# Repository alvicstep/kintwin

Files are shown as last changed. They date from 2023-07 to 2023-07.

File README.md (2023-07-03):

# KinTwin
KinTwin is a fork of [KinBP](https://github.com/DmNosachev/KinBP). It is a drop-in replacement of a controller and thumb cluster PCB boards for [Kinesis Contoured keyboards](https://deskthority.net/wiki/Kinesis_Contoured).

## Goals
- Replace stock firmware with [QMK](https://docs.qmk.fm/#/) open source firmware
- Show clear and concise BOM (bill of materials) required for the upgrade depending on Kinesis keyboard model

## Included PCBs

||
|-|
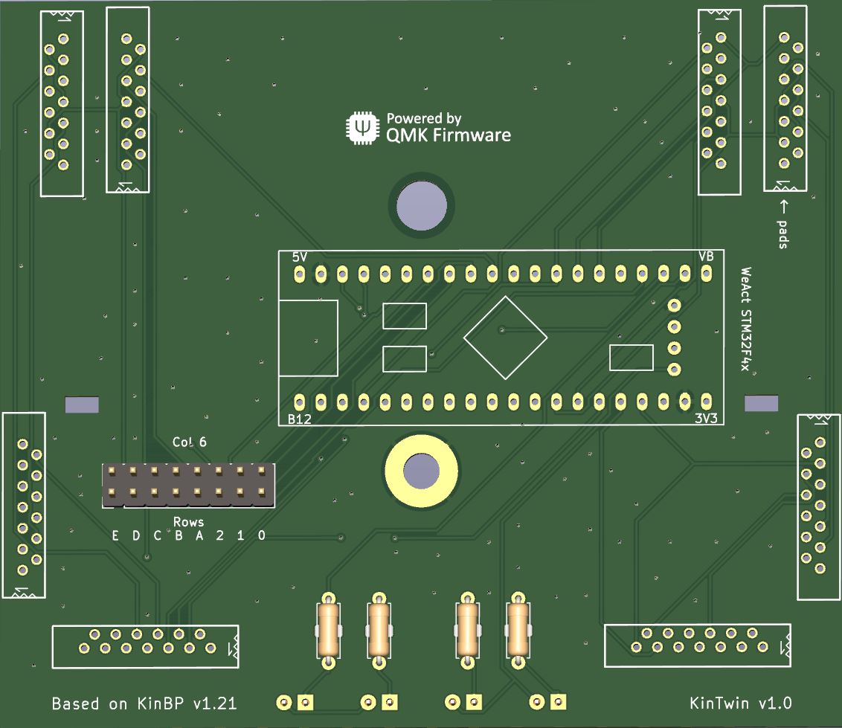
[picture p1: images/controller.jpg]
|        
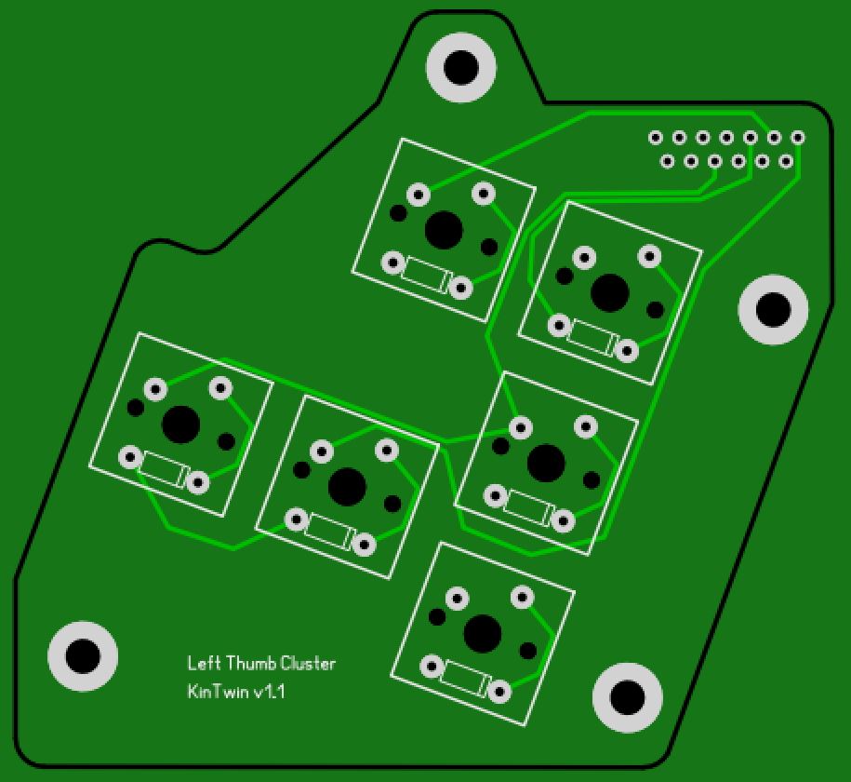
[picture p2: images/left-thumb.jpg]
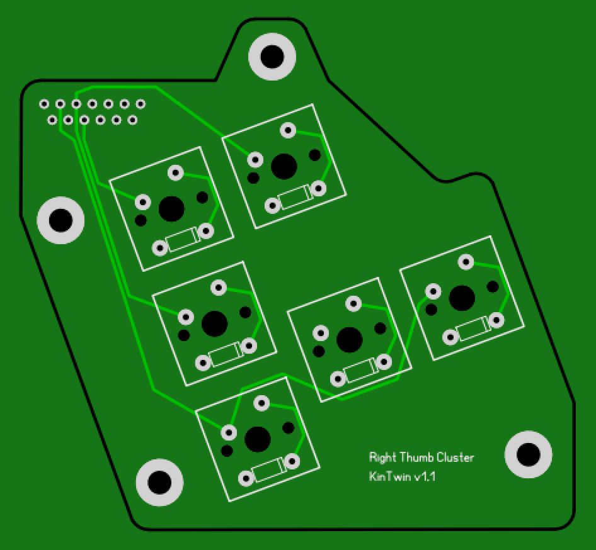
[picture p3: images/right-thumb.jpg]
| 
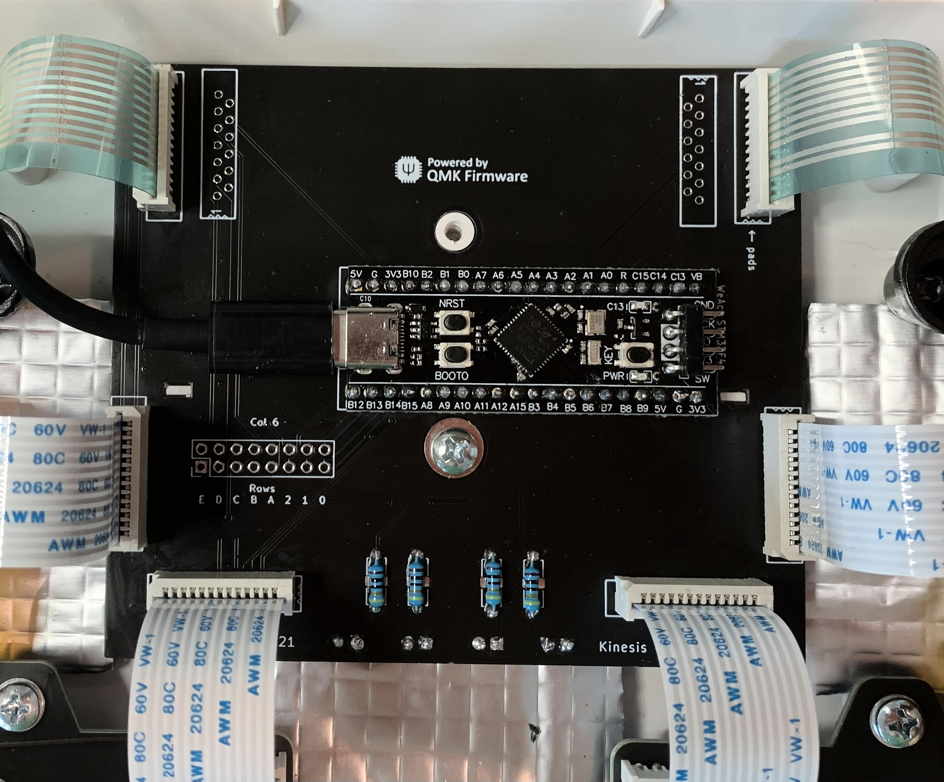
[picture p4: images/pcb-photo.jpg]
|  
> **Warning**  
> I have recently updated the design of thumb cluster PCB from v1.0 to v1.1 
> The changes are cosmetic and should not affect functionality, but I did not order the new boards to be able to confirm that they still work.  
> Changes include: 
> - moved silk screen of the FPC connector pad to the correct side
> - changed mounting holes of the FPC connector pad to be plated

## Comparison with KinBP
- The controller board is a simplified version on KinBP board. It uses **WeAct Studio STM32F401** development board
- KinTwin controller board uses only FPC connectors to interface with other PCB boards. In that regard it has the same design as stock Kinesis Advantage II
- KinTwin controller does not support 10-pin 2.54mm headers which are used to connect the controller to thumb cluster boards
- Similar to KinBP repo, KinTwin includes PCB boards for thumb clusters. They are functionally identical to stock Kinesis Advantage II. Unlike KinBP, these PCBs are not reversible (hence there are 2 of them). Also, similar to stock boards, they use through-hole diodes and FPC connectors
- The controller board was originally designed in KiCad by [DmNosachev](https://github.com/DmNosachev). KinTwin controller board is a clone of KinBP which was slightly modified by removing extra connector pads. 
- Thumb cluster boards were designed in [Sprint Layout 6.0](https://www.electronic-software-shop.com/lng/en/electronic-software/sprint-layout-60.html?language=en)

## Controller compatibility with top row PCBs, keywell PCBs and thumb cluster PCBs

|Keyboard Model |Top row PCBs|Keywell PCBs|Thumb cluster PCBs|
|---|---|---|---|
|KB600 (Advantage II) |Yes |Yes |Yes |
|KB500 (Advantage) |Yes |Yes |No  * |
|KB13x (Essential, Classic, Professional) |Yes |Yes |No  * |
|100/110/120 ** |No |No |No  * |

\* These keyboards require custom thumb cluster PCBs which are provided in the repo\
** You are likely not going to find these keyboards in the wild. They are 20+ years old

## BOM (common for all models)
|Name |Quantity  |Image  |
|---|---|---|
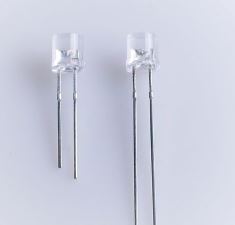
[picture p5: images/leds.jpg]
|3mm Blue LED Diodes (DC 3.0V-3.2V (IF=20mA) / 0.06 Watts / 2pin) | 4 | |
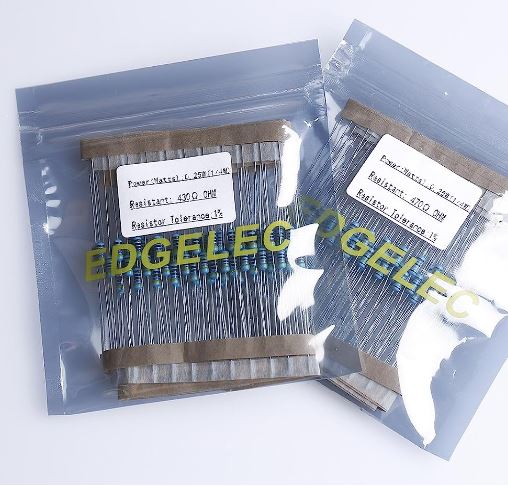
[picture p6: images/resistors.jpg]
|430ohm (For DC 6-12V) 1/4 Watt Metal Film Resistors | 4 | |
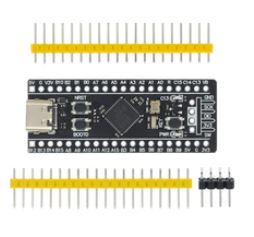
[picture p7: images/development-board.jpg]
|STM32F401 development board | 1 ||
|Controller board | 1 | |

## BOM (for model KB600)
|Name |Quantity  |Image  |
|---|---|---|
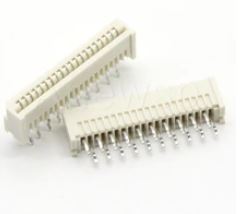
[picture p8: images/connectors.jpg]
|13-pin straight FPC connectors | 6 | |

## BOM (for model KB500) 

|Name |Quantity |Image |
|---|---|---|
|13-pin straight FPC connectors | 8 | |
|Left thumb cluster board | 1 | |
|Right thumb cluster board | 1 | |
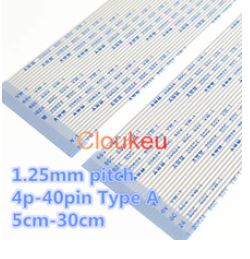
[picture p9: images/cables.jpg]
|FPC flexible flat cables (FFC1.25-60mm)  | 2 | |
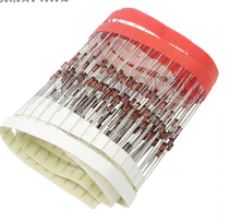
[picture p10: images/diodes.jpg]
|Diodes (1N4148 DO-35 IN4148) for thumb cluster PCBs| 12 ||
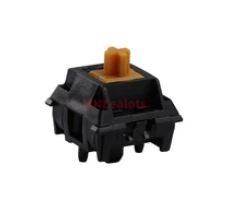
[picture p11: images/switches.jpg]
|Keyboard switches for thumb cluster PCBs | 12 | |

## BOM (for models KB13x)

|Name |Quantity |Image |
|---|---|---|
|13-pin straight FPC connectors | 6 | |
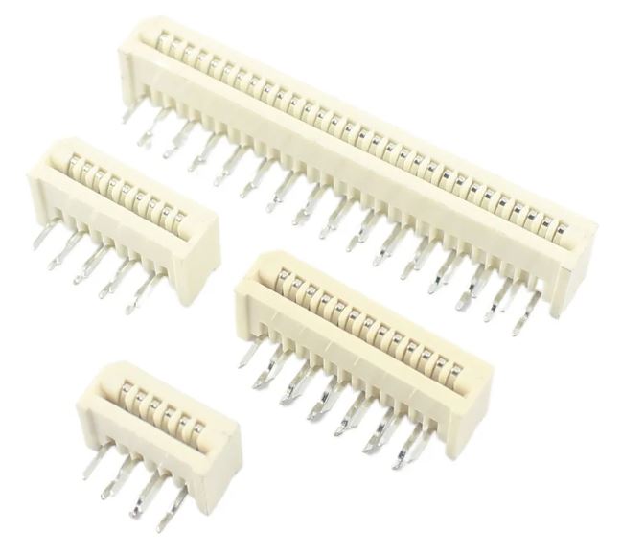
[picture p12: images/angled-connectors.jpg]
|13-pin angled FPC connectors | 2 ||  
|Left thumb cluster board | 1 | |
|Right thumb cluster board | 1 | |
|FPC flexible flat cables (FFC1.25-60mm)  | 2 | |
|Diodes (1N4148 DO-35 IN4148) for thumb cluster PCBs| 12 | |
|Keyboard switches for thumb cluster PCBs | 12 | |

## QMK Related Topics

Read about the custom QMK layout which I have designed [here](/layouts/readme.md)

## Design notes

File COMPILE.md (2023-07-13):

# Compiling/Flashing

1. I submitted PR which contains the kintwin controller files and soft_dev keypam but it is still being reviewed. There is nothing else for me to do but wait. In the meantime, you can use the forked repo which I used for PR to flash the keyboard with new keymap

    - QMK fork url: https://github.com/alvicstep/qmk_firmware/tree/kintwin
    - kintwin controller directory url: https://github.com/alvicstep/qmk_firmware/tree/kintwin/keyboards/kinesis/kintwin
	- keymap url: https://github.com/alvicstep/qmk_firmware/tree/kintwin/keyboards/kinesis/keymaps/soft_dev

2. Here is a PR that I submitted for review: https://github.com/qmk/qmk_firmware/pull/21453
 
3. There is only one controller. Controller details can be found here: https://github.com/alvicstep/kintwin

4. Compiling/flashing process is the same as for any other board. QMK documentation: https://docs.qmk.fm/#/newbs_getting_started
	- download my fork of QMK (link above)
	- install QMK MSYS in order to compile the firmware: https://msys.qmk.fm  The wizard will ask whether you want to dowload QMK. Reply "no" because you already have a forked repo.
		You will then have to point MSYS to the directory where you cloned QMK fork.
		Run the following command in MSYS: `qmk config user.qmk_home=<QMK fork directory>`
		A backslash must be escaped with another backslash in the path. Example: `qmk config user.qmk_home=C:\\git\\qmk_firmware` 
		
	- compile framework. Run the following command in QMK MSYS: `qmk compile -kb kinesis/kintwin -km soft_dev`
	- download QMK Toolbox from here: https://github.com/qmk/qmk_toolbox/releases
	- put the keyboard in bootloader mode: press "Pgrogrm" button on the keyboard. This is top right button on the keyboard
	- set path in QMK Toolbox to the "bin" file which you compiled. Click "Flash" button in QMK Toolbox
	
5. To update keymap: make changes to the keymap in the forked repo here: `/keyboards/kinesis/keymaps/soft_dev/keymap.c`
   You can use any other keymap in "keymaps" directory as your base keymap. But please make sure the keymap contains bootloader mapping (code QK_BOOT). Otherwise you will have to perform physical reset by pushing buttons on the controller board itself: Hold `'boot0'` button on MCU board, press `'reset'`, then release `'boot0'`
   
   - Run the following command in QMK MSYS: `qmk compile -kb kinesis/kintwin -km <keymap name>`
   - Flash the firmware as described above

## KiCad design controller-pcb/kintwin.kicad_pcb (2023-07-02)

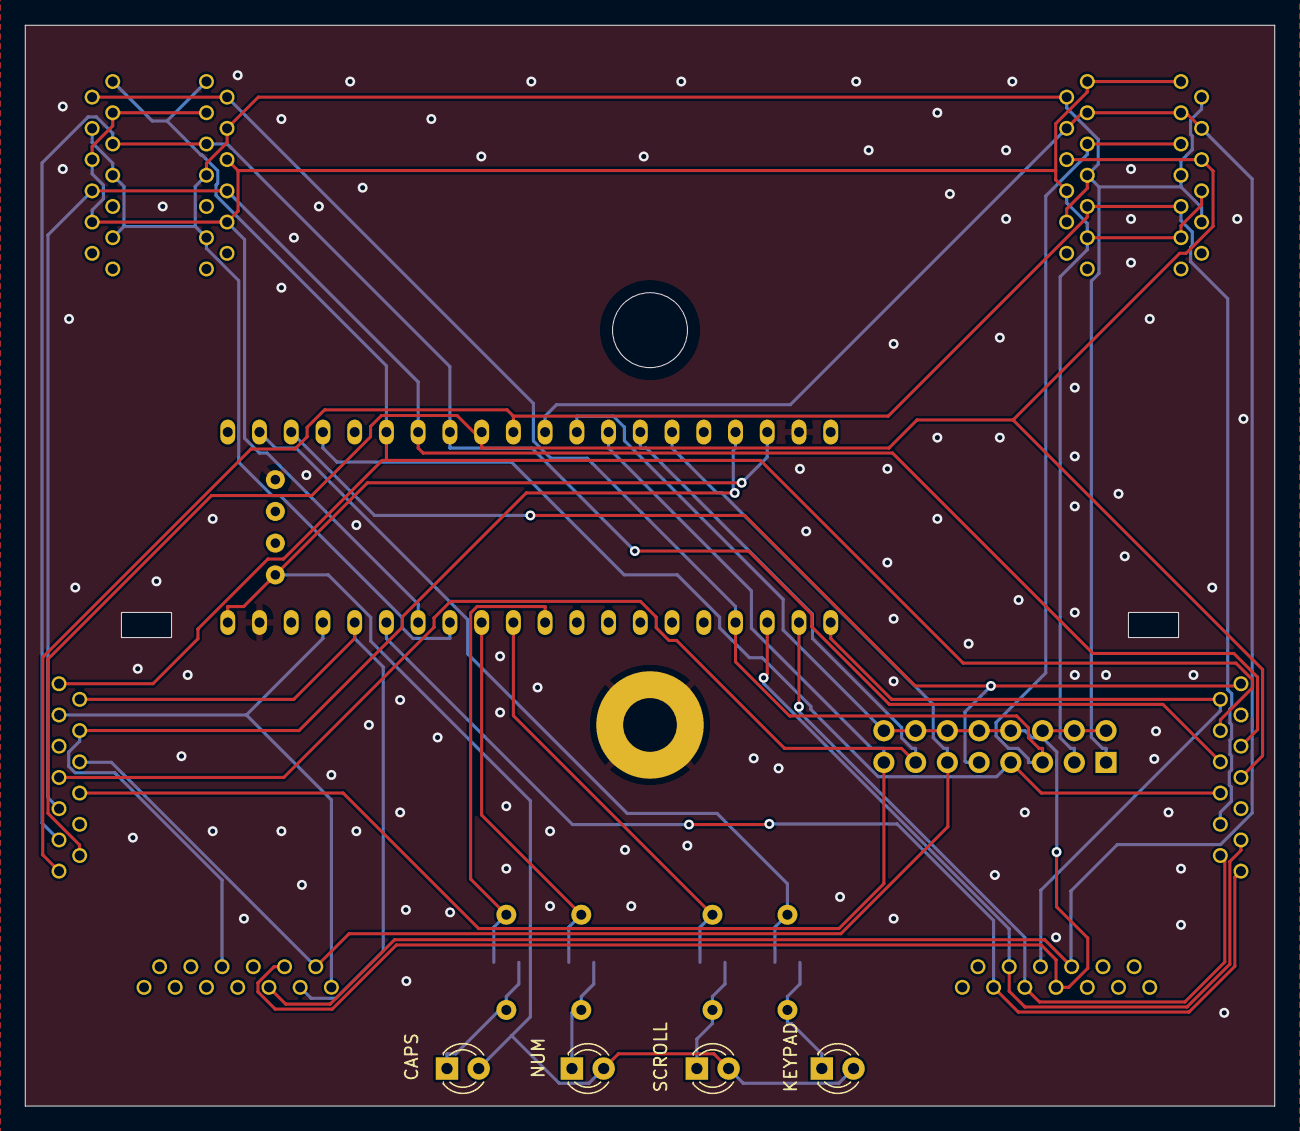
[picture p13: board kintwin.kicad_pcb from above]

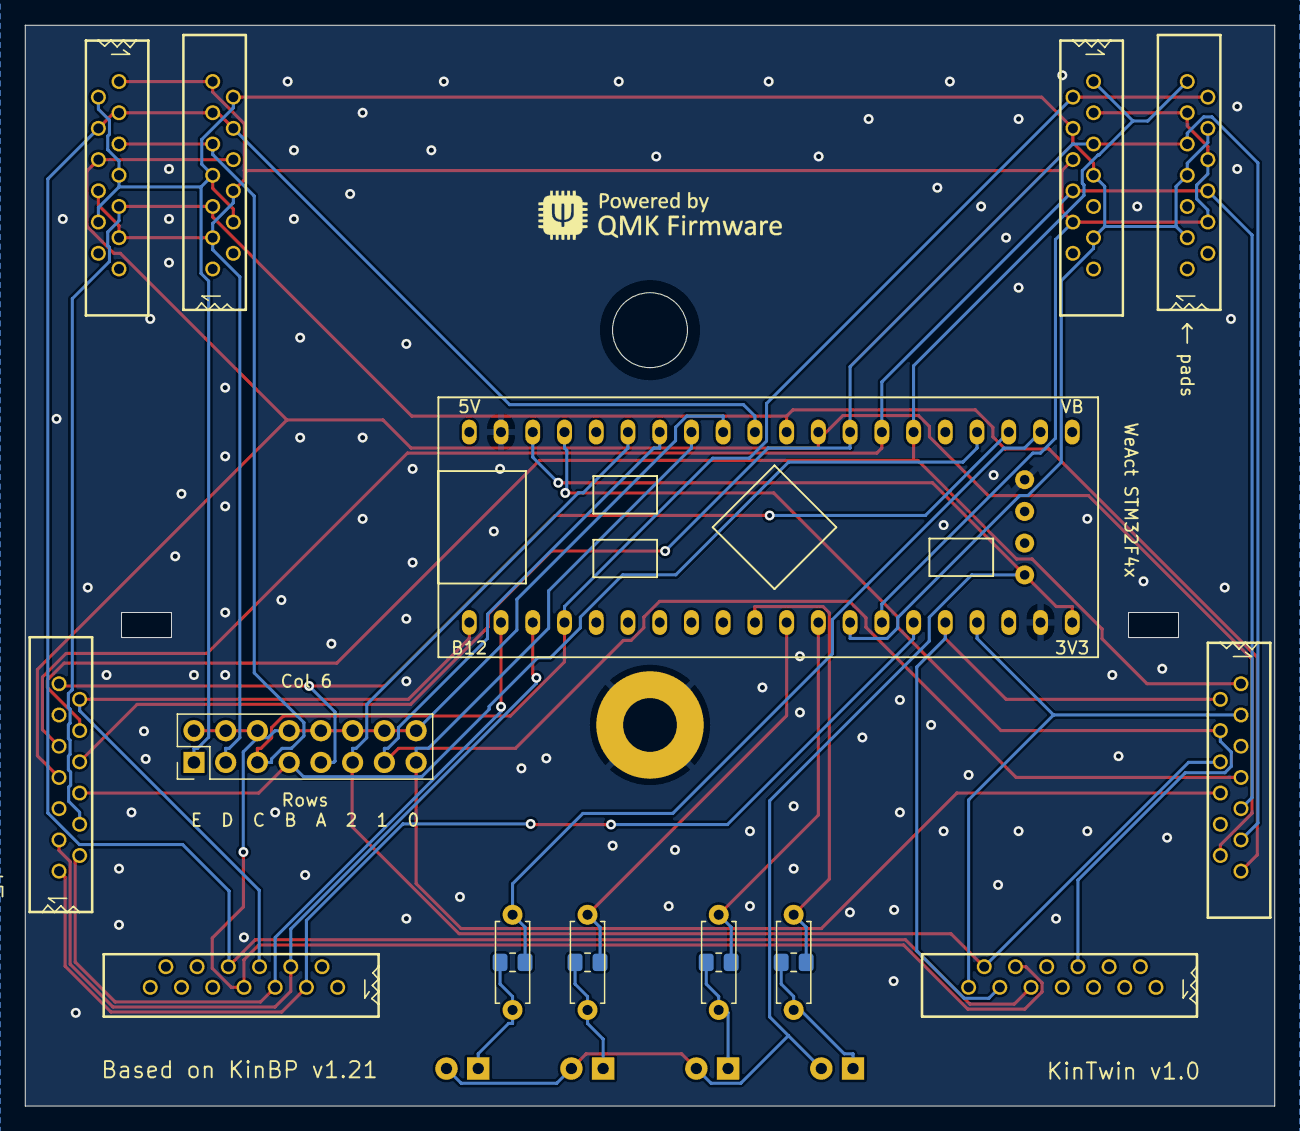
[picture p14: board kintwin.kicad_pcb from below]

Board: 2 copper layers, 100.0 x 86.5 mm, 24 parts (18 on the bottom side), 32 nets.

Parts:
H1: mounting pad; MountingHole_4.3mm_M4_Pad
H2: mounting pad; MountingHole_6mm
J1, J2: LEFT_TOP; 39-53-2135
J3, J4: RIGHT_TOP; 39-53-2135
J5: RIGHT_KEYWELL; 39-53-2135
J6: LEFT_KEYWELL; 39-53-2135
J9: Conn_02x08_Odd_Even; PinHeader_2x08_P2.54mm_Vertical
J10: LEFT_THUMB; 39-53-2135
J11: RIGHT_THUMB; 39-53-2135
LED1, LED2, LED3, LED4: 3mm; LED_D3.0mm
R1, R2, R3, R4: 1k; R_0805_2012Metric_Pad1.20x1.40mm_HandSolder
R5, R6, R7, R8: 1k; R_Axial_DIN0207_L6.3mm_D2.5mm_P7.62mm_Horizontal
U1: weact_STM32F4x1; STM32F4x1_MiniF4

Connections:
/3V3: LED1.2 (A), LED2.2 (A), LED3.2 (A), LED4.2 (A), U1.20 (3V3), U1.38 (3V3), U1.41 (3V3)
COL_0: J1.1, J2.13, J5.10, J6.1, U1.26 (A0)
COL_1: J1.8, J2.6, J5.9, J6.9, U1.27 (A1)
COL_2: J1.5, J2.9, J5.8, J6.11, U1.28 (A2)
COL_3: J3.6, J4.8, J5.7, J6.12, U1.29 (A3)
COL_4: J3.9, J4.5, J5.4, J6.13, U1.30 (A4)
COL_5: J3.3, J3.4, J4.10, J4.11, J10.9, J11.8, U1.31 (A5)
COL_6: J9.2, J9.4, J9.6, J9.8, J9.10, J9.12, J9.14, J9.16, J10.10, J11.7, U1.32 (A6)
GND: H1.1, U1.19 (GND), U1.39 (GND), U1.44 (GND)
LED_CAPS: R4.1, R8.1, U1.10 (A15)
LED_CAPS_R: LED4.1 (K), R4.2, R8.2
LED_KPD: R1.1, R5.1, U1.22 (C13)
LED_KPD_R: LED1.1 (K), R1.2, R5.2
LED_NUM: R3.1, R7.1, U1.12 (B4)
LED_NUM_R: LED3.1 (K), R3.2, R7.2
LED_SCRL: R2.1, R6.1, U1.11 (B3)
LED_SCRL_R: LED2.1 (K), R2.2, R6.2
ROW_0: J6.8, J9.15, U1.33 (A7)
ROW_1: J6.7, J9.13, U1.34 (B0)
ROW_2: J6.6, J9.11, J10.12, U1.35 (B1)
ROW_3: J6.4, J10.6, U1.37 (B10)
ROW_4: J6.3, J10.13, U1.17 (B9)
ROW_5: J6.2, J10.11, U1.16 (B8)
ROW_6: J5.1, J11.3, U1.15 (B7)
ROW_7: J5.3, J11.4, U1.3 (B14)
ROW_8: J5.2, J11.5, U1.2 (B13)
ROW_9: J5.12, J11.6, U1.1 (B12)
ROW_A: J5.13, J9.9, U1.23 (C14)
ROW_B: J5.6, J9.7, U1.24 (C15)
ROW_C: J1.2, J2.12, J3.5, J4.9, J9.5, U1.4 (B15)
ROW_D: J1.3, J1.6, J1.10, J2.4, J2.8, J2.11, J3.1, J3.8, J3.11, J4.3, J4.6, J4.13, J9.3, U1.14 (B6)
ROW_E: J1.4, J1.7, J1.11, J2.3, J2.7, J2.10, J3.2, J3.7, J3.10, J4.4, J4.7, J4.12, J9.1, U1.13 (B5)

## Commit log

2023-07-02 Original commit
    [kinBP.kicad_pcb, kinbp-thumb-pcb.kicad_pcb, kinbp-thumb-pcb.kicad_sch]
2023-07-02 Generated gerber files; updated readme; added warning that the thumb board changes were not tested
    [kinBP.kicad_pcb, kinBP.kicad_sch, kintwin.kicad_pcb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]
2023-07-03 Added photo ot PCB
